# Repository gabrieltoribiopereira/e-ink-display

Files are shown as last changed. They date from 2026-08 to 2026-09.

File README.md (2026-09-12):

# e-ink display

A 7.5" e-paper dashboard that shows the time, the weather, my google calendar, my
google tasks and my habit tracker. An ESP32 wakes up, downloads the image and goes
back to sleep.

# Components

| Universal e-Paper Raw Panel Driver Board, ESP32 WiFi / Bluetooth Wireless | $14,99  |
| --- | --- |
| 800×480, 7.5inch E-Ink display HAT for Raspberry Pi | $47,99  |
| 974058 3000mAh Lipo Battery 3.7V Lithium Polymer Batteries PH2P for Massage Meter GPS Navigator Aeromodelling Rechargeable Cell | 10,99 € |
| 20/50/100PCS/LOT NEW TTP223 Touch Button Module Capacitor Type Single Channel Self Locking Touch Switch Sensor for Arduino | 2,12 €  |
| Frame | 0,00 €  |
| 2/5PCS 5V 1A Micro/Type-c/Mini 18650 TP4056 Lithium Battery Charger Module Charging Board With Protection Dual Functions Li-ion | 1,74€ |
# Explanation

I'll explain some of the tecnical desicions.

First of all I decided to use an esp32 instead of a raspberry pi zero 2 because the
esp32 in its sleep mode consumes so much less electricity.

You can replace the TTP223 for buttons or wathever you like.

The hour will not refresh automaticly because I rather save battery, you have to
wake it first (its not programmed yet because i dont have the esp32 yet).

E-ink keeps the image with **zero power**, that's the whole point. It only costs
battery when it changes. So the esp32 sleeps, wakes up every X minutes, asks if
there is anything new, and only redraws when the image actually changed.

The web renders the screens, a script turns them into a 2 bits per pixel image
(4 grays, 96000 bytes exactly) and the esp32 downloads that raw file. It can't use
a `.h` file because it can't compile anything at runtime, and the `.h` is 6 times
bigger anyway (600KB of text for 96KB of data).

I know that there's 3 buttons in the habit tracker menu that don't work. It's just that
I didn't want to program them because I don't think I will use them. 

# How to install

If you want to replicate the e-ink display there's a lot of thing you need to do.
I'll try my best to explain.

First of all install the repository:

```bash
git clone https://github.com/gabrieltoribiopereira/e-ink-display.git
cd e-ink-display

python3 -m venv .venv
.venv/bin/pip install -r scripts/requirements.txt

cd server && npm ci && npx playwright install --with-deps chromium && cd ..
```

If you are on Arch (or anything that is not Debian/Ubuntu) drop the `--with-deps`,
it uses apt-get behind the scenes so it will fail:

```bash
cd server && npm ci && npx playwright install chromium && cd ..
```

# Supabase

You'll need an account on supabase.com. First of all create a project.

### Create your user

Authentication -> Users -> **Add user**. Write down the email and the password,
you'll need them later. There is no sign up form in the web on purpose, it's only
for me.

### Create the tables

Once the project is created go to SQL editor

paste and execute the following code:

```sql
create table habitos (
  usuario uuid primary key references auth.users(id) on delete cascade,
  datos jsonb not null default '{"habitos":[],"registro":{}}',
  actualizado timestamptz default now()
);
create table ajustes (
  usuario uuid primary key references auth.users(id) on delete cascade,
  ics text, lat numeric default 41.6, lon numeric default 2.3
);
create table tareas (
  usuario uuid primary key references auth.users(id) on delete cascade,
  datos jsonb not null default '[]',
  actualizado timestamptz default now()
);

alter table habitos enable row level security;
alter table ajustes enable row level security;
alter table tareas  enable row level security;

create policy "solo lo mio" on habitos for all
  using (auth.uid() = usuario) with check (auth.uid() = usuario);
create policy "solo lo mio" on ajustes for all
  using (auth.uid() = usuario) with check (auth.uid() = usuario);
create policy "solo lo mio" on tareas for all
  using (auth.uid() = usuario) with check (auth.uid() = usuario);
```

The `enable row level security` part is not optional. The anon key is public (it
goes inside config.js and anyone can read it), so those policies are the only thing
stopping other people from reading your habits and tasks.

### Create the bucket

Storage -> New bucket -> name it `frames`. **Turn OFF the "Public bucket" switch**,
the frames are pictures of your calendar and your tasks.


### Save the keys

Project Settings -> API Keys -> save these two (the `service_role` one is inside
the "Legacy API keys" tab):


Project Settings -> Data API -> save the Project URL. If you can't find it, it's
always `https://<project-ref>.supabase.co` and the ref is in the url of the
dashboard.

# Google

You will need google credentials to use the calendar and the tasks.

### The calendar url

Google Calendar -> my calendars -> 3 dots -> Settings -> **Integrate calendar** ->
copy the **secret address in iCal format**.

Careful with this one, that url is the key to your whole calendar. Anyone who has
it can read all your events without any password.

### The OAuth credentials

console.cloud.google.com -> new project -> **enable the Google Tasks API** first.

Then OAuth consent screen -> **publish the app**. If you leave it in "Testing"
google kills your token every 7 days and the cron stops syncing (it happened to me).

Then Credentials -> Create credentials -> OAuth client ID -> **type: Desktop app**.
The type matters, gtasks.py uses InstalledAppFlow and it only works with Desktop.

Click on the client you just created and hit **Download JSON**. You need the whole
file, not just the client ID.

# The secrets folder

This folder is in .gitignore, that's why you don't see it in the repo. You have to
create it:

```bash
mkdir -p secrets

# the OAuth json you downloaded from google
cp ~/Downloads/client_secret_*.json secrets/credentials.json

# the account the screenshot browser uses to log in.
# same email and password of the supabase user you created before
cat > secrets/display.json <<'EOF'
{"email": "you@example.com", "password": "..."}
EOF

# the ESP32 password. You invent this one, nobody gives it to you
python3 -c "import secrets; print(secrets.token_urlsafe(32))" > secrets/device-token.txt
```

And `secrets/config.js`, which is the one the web reads:

```js
const CONFIG = {
  ICS: "https://calendar.google.com/calendar/ical/.../basic.ics",
  LAT: 41.6,
  LON: 2.3,
  SUPABASE_URL: "https://xxxx.supabase.co",
  SUPABASE_ANON_KEY: "eyJ...",
};
```

There is a template in `web/config.example.js` if you prefer to copy that one.

### Authorize google (only once)

```bash
.venv/bin/python scripts/gtasks.py
```

It opens the browser, you accept, and it creates `secrets/token.json`. From then on
it refreshes by itself, you don't have to authorize again.

# Configure weather

Put your latitude and longitude in `secrets/config.js` (LAT and LON, up there). You
get them from google maps, right click anywhere and it copies them.

The first time you log in, the web copies those values into the `ajustes` table of
supabase and **from then on it reads them from there**, not from config.js. That's
because the ICS url can't live in config.js: that file is served without login, so
on netlify anybody could open /config.js and read your whole calendar.

So if you want to change the location later, config.js will do nothing, you have to
change the table:

```sql
update ajustes set lat = 40.4168, lon = -3.7038;
```

(I named the file ajustes.js instead of settings.js and I don't want to rename it
now that everything works XD, for the next project I'll do everything in english
from the start)

# Github secrets

This part is only if you want it running in the cloud, so the display keeps working
with your computer turned off. Github actions renders the screens every 20 minutes
and uploads them to supabase.

Go to your repo -> Settings -> Secrets and variables -> Actions -> New repository
secret, and create these nine:

| Secret | Where you get it |
|---|---|
| `SUPABASE_URL` | the Project URL from before |
| `SUPABASE_ANON_KEY` | the anon key |
| `SUPABASE_SERVICE_ROLE` | the service_role key (the one that warns about RLS) |
| `CAL_ICS` | the secret iCal url |
| `DISPLAY_EMAIL` | the email of the supabase user |
| `DISPLAY_PASSWORD` | its password |
| `GOOGLE_CREDENTIALS` | the whole content of `secrets/credentials.json` |
| `GOOGLE_TOKEN` | the whole content of `secrets/token.json` |
| `DEVICE_TOKEN` | the same one you put in `secrets/device-token.txt` |

The name goes in the **Name** field (only letters, numbers and `_`, that's why it
rejects an `@`) and the value in the big box below.

# The edge function

The frames bucket is private, so the esp32 can't read it directly. This function
checks its token and gives it the file:

```bash
npx supabase login
npx supabase link --project-ref YOUR_REF
npx supabase secrets set DEVICE_TOKEN=<the same one you generated before>
npx supabase functions deploy frame --no-verify-jwt
```

`--no-verify-jwt` is mandatory. The esp32 has no supabase session, so if you leave
the jwt check on, supabase rejects the request before it even reaches the code.

I didn't give the esp32 the supabase keys on purpose. If someone steals the device
the only thing they can do is download 4 pictures, not read my database.

# Deploy via netlify
(you could use other hosts i chose this because I used before and I'm used to it.)
netlify.com -> Add new site -> Import an existing project -> github -> pick the repo.

**Don't touch** the build command or the publish directory, netlify reads them from
`netlify.toml`.

Before deploying, go to Environment variables and add two:

- `SUPABASE_URL`
- `SUPABASE_ANON_KEY` -> the **anon** one, not the service role

If you paste the wrong one the build fails on purpose with "SUPABASE_ANON_KEY parece
la clave de servicio". I put that check there because that key skips RLS and
publishing it in a static file gives anybody full access to the database.

Then hit Deploy. From now on every git push deploys by itself.

Netlify does **not** replace github actions. The frames still need a real chromium
rendering them and netlify only serves files. Netlify is so I can open the dashboard
from my phone.

# Run it

Now that everything is set up:

```bash
cd server
npm start        # everything: web + chromium + screenshots
npm run web      # only the web, starts instantly, no screenshots
```

Open http://localhost:8002 and log in with the supabase user. Use `npm run web` when
you are just editing the web, it doesn't launch chromium so it's way faster.

Press a button and save the image it returns (this goes in another terminal, change
the x for the button number(1-4)):

```bash
curl -s -X POST -d 'x' http://localhost:8002/boton -o prueba.png 

# see the current screen without pressing anything
curl -s http://localhost:8002/captura.png -o actual.png
```

To test what the esp32 will do:

```bash
.venv/bin/python scripts/simular-esp32.py 1    # press button 1
python3 scripts/ver-bin.py esp32-sim/inicio.bin --abrir
```

Run the same button twice. The second time it should say "sin cambios" and not
download anything, that's the hash check that saves the battery.

Only from the `inicio` screen you can jump to another screen. From the rest, button
1 takes you back and the others do things inside that screen.

If the port gets stuck: `fuser -k 8002/tcp`

## Hardware setup

Connect everything the same way that in CAD/Schematic. Print the case that is located in CAD/case, I encourage you to create your own case because I'm not an expert using cad sofware so the design is not perfect. 

## ESP32 setup

The firmware lives in "esp32/esp32.ino". It wakes up, downloads the frames from supabase, draws the screen and goes back to deepsleep. The buttons switch screens without wifi, everything is alredy stored in the flash.

### Install Arduino IDE

### Create esp32/config.h
This file is in .gitignore on purpose, it carries your wifi password and the device token. Open `esp32/esp32.ino` in the IDE (File -> Open), then create the config next to it: click the three dots at the right of the tab bar -> New Tab,name it `config.h` and paste:

```cpp
#pragma once
#define WIFI_SSID     "YourWifi"
#define WIFI_PASS     "your-password"
#define DEVICE_TOKEN  "the same one from secrets/device-token.txt"
#define FRAMES_URL    "https://xxxx.supabase.co/functions/v1/frame"
#define INTERVAL_S    (20 * 60)
#define FOUR_GRAYS    1
```

### flash it 

connect the display's flat cable to the driver board. Then plug the usb. 

In the IDE:

1. Tools-> Board esp32 -> **Esp32 Dev Module**
2. Tools-> Port-> pick the one that appears when you plug the board
3. Press the **upload** button.

### Check that it works open tools -> serial monitor and set it to **115200 baud**. Press the EN button on the board to see it boot from the start. First boot should look like this:

```
Wake 1: first boot
Connecting to WiFi.... connected, IP 192.168.1.42
  inicio            downloaded
  calendario        downloaded
  calendario-semana downloaded
  todo              downloaded
  habitos           downloaded
Sync done: 5 of 5 updated
Drawing inicio
Going to sleep
```

---

If there is something about I wast clear enough let me know please. I wrote the
readme after finish the project so I may had forget some steps.

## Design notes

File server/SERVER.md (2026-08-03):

# Explicación de como usar el server

El server sirve la web de `web/`, la abre en un Chromium propio y captura
`.contenedor` para generar los `.h` que consume el ESP32.

Puerto: **8002**

## 0 requisito: cuenta del display

La web tiene login, y el navegador que abre el server arranca sin sesión.
Hay que darle una cuenta dedicada en `secrets/display.json`:

```json
{ "email": "display@ejemplo.com", "password": "..." }
```

Sin ese archivo el server arranca igual, pero `/boton` y `/captura.png`
devuelven error porque el dashboard está oculto.

## 1 empezar el server:

```
cd server
npm start          # o: node server.js
```

Luego abre <http://localhost:8002>.

### solo ver la web (sin capturas)

```
npm run web        # o: node server.js --solo-web
```

Arranca al instante porque no lanza Chromium. Sirve la web igual, pero
`/boton` y `/captura.png` devuelven 503. Es el modo para maquetar.

> No vale abrir `web/index.html` a pelo con `file://`: `config.js` se sirve
> desde `secrets/` y `tareas.json` desde `data/`, ninguno de los dos esta
> dentro de `web/`. Ademas Supabase Auth necesita un origen `http`.

## 1.5 tareas de Google Tasks

El server sincroniza `data/tareas.json` solo, sin que tengas que ejecutar nada:

- al arrancar
- cada 10 minutos en segundo plano
- justo antes de capturar la pantalla To-Do (y le pide a la página que recargue)

Como mucho llama a Google una vez cada 10 min, aunque captures sin parar.

**Requisito:** `secrets/token.json`. Se crea la primera vez, autorizando a mano:

```
.venv/bin/python scripts/gtasks.py
```

Ojo con el intérprete: `gtasks.py` necesita el del **venv** (tiene las librerías de
Google), y `convertirimagenendosbits.py` el del **sistema** (tiene Pillow).
Ninguno de los dos sirve para ambos.

Sin `token.json` el server arranca igual y avisa por consola; el resto sigue
funcionando, solo que el To-Do se queda con los últimos datos guardados.

## 2 ejecutar botón:
se tiene que hacer en otra terminal:

```
curl -X POST http://localhost:8002/boton -d "2" -o boton2.png
```

Las capturas y los `.h` se guardan solos en `output/`.

## 3 ver la pantalla actual sin pulsar nada:

```
curl -s http://localhost:8002/captura.png -o actual.png
```

## 4(extra) ejecutar en segundo plano

```
node server.js &
```

## en caso de que haya otro server hay que matarlo:

```
fuser -k 8002/tcp
```

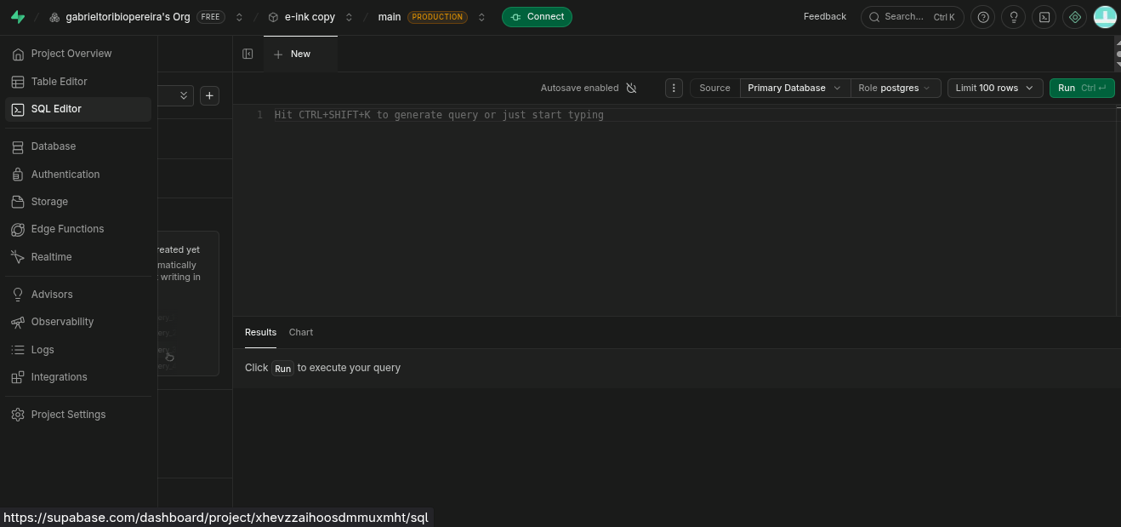
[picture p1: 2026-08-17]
images/image.png

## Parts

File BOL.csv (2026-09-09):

Name | Price | Ship expenses | Link
Universal e-Paper Raw Panel Driver Board, ESP32 WiFi / Bluetooth Wireless | $14,99 |  | https://www.waveshare.com/e-paper-esp32-driver-board.htm
800×480, 7.5inch E-Ink display HAT for Raspberry Pi | $47,99 | $14,00 | https://www.waveshare.com/product/7.5inch-e-paper.htm
974058 3000mAh Lipo Battery 3.7V Lithium Polymer Batteries PH2P for Massage Meter GPS Navigator Aeromodelling Rechargeable Cell | 10,99 € |  | https://es.aliexpress.com/item/1005008979897440.html?mp=1
20/50/100PCS/LOT NEW TTP223 Touch Button Module Capacitor Type Single Channel Self Locking Touch Switch Sensor for Arduino | 2,12 € | 8,14 € | https://es.aliexpress.com/item/1005006246380749.html?mp=1&gatewayAdapt=glo2esp
Frame | 0,00 € | 0 | https://www.leroymerlin.es/productos/marco-natural-wood-natural-13x18cm-71670242.html
2/5PCS 5V 1A Micro/Type-c/Mini 18650 TP4056 Lithium Battery Charger Module Charging Board With Protection Dual Functions Li-ion | 1,74€ |  | https://es.aliexpress.com/item/1005006043031985.html
Total: | €89,43
$ Total: | $103,62
0,8631

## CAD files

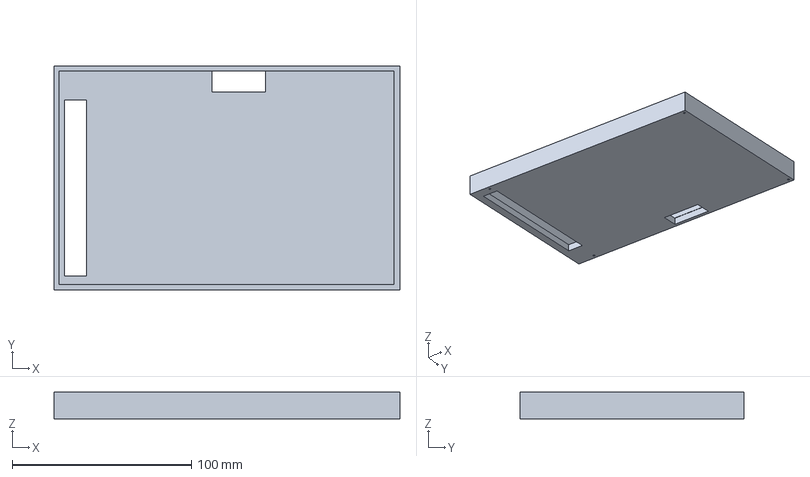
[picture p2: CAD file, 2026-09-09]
CAD/case/body.3mf
193.1 x 125.1 x 15.0 mm

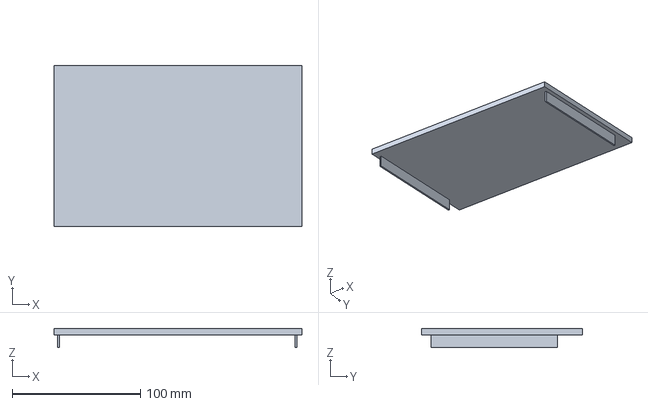
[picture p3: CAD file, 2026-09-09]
CAD/case/back.3mf
193.1 x 125.0 x 15.0 mm

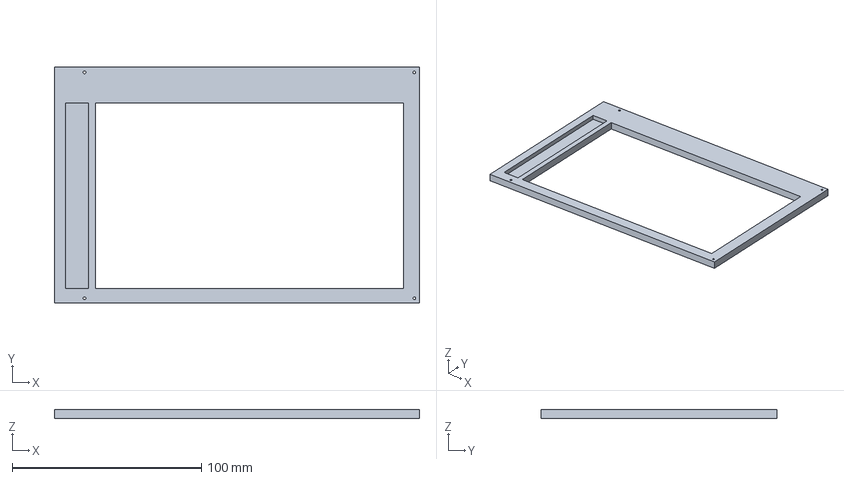
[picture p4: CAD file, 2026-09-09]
CAD/case/frame001.3mf
193.1 x 125.1 x 5.00 mm

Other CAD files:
CAD/case/frame.stl
CAD/case/back.stl
CAD/case/body.stl

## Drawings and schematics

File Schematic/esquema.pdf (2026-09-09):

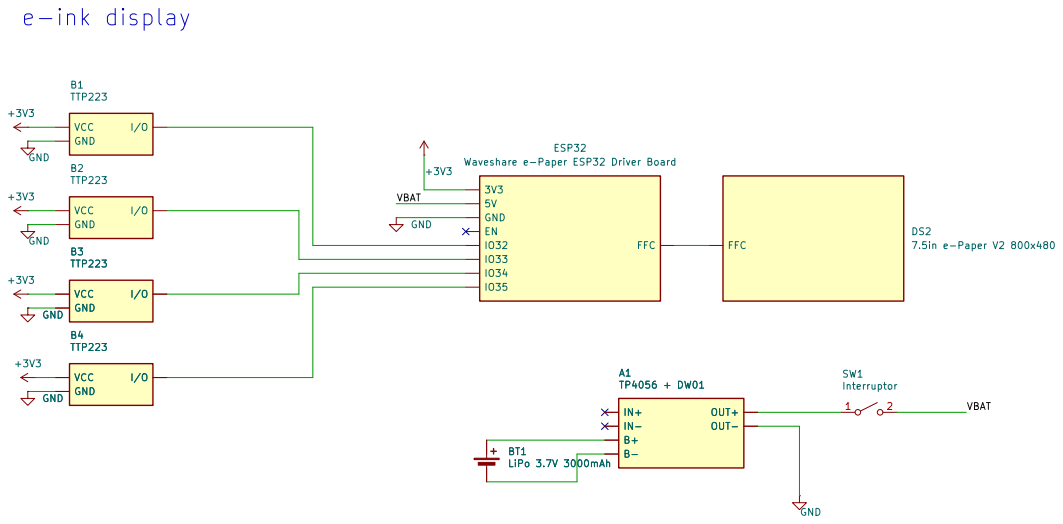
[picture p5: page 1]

ESP32 Waveshare e-Paper ESP32 Driver Board BT1

Modulos comerciales: no hay PCB que fabricar
Panel 7.5in e-Paper V2 + Waveshare ESP32 Driver Board

Sheet: /
File: esquema.kicad_sch
Title: e-ink display - conexiones

Size: A3 | Rev: 1 | F Date:
KiCad E.D.A. 10.0.5 | Id: 1/1

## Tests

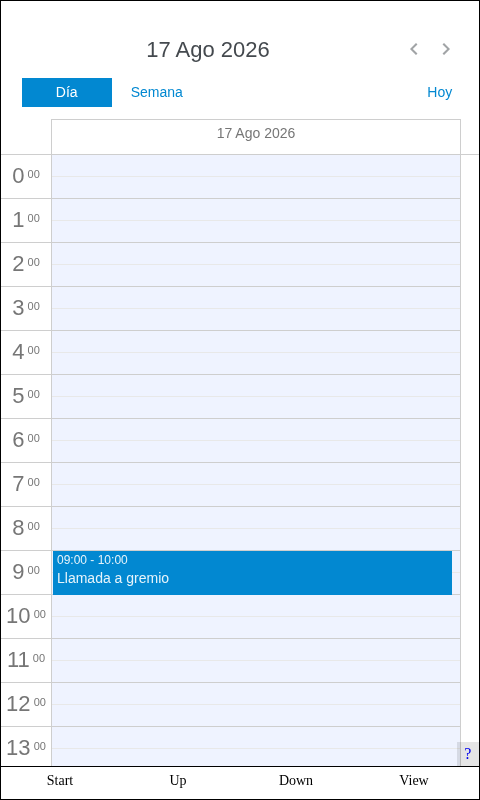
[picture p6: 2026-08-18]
images/prueba.png

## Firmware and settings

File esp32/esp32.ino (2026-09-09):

#include "config.h"
#include <WiFi.h>
#include <WiFiClientSecure.h>
#include <HTTPClient.h>
#include <ArduinoJson.h>
#include <LittleFS.h>
#include <SPI.h>
#include <mbedtls/sha256.h>

const int PIN_CLK = 13, PIN_DIN = 14, PIN_CS = 15;
const int PIN_BUSY = 25, PIN_RST = 26, PIN_DC = 27;
const int BUTTONS[4] = {32, 33, 34, 35};

const char* SCREENS[] = {"inicio", "calendario", "calendario-semana", "todo", "habitos"};
const int NUM_SCREENS = 5;
const int FRAME_BYTES = 800 * 480 * 2 / 8;

RTC_DATA_ATTR int wakeCount = 0;
RTC_DATA_ATTR int currentScreen = 0;

void cmd(uint8_t c) {
  digitalWrite(PIN_DC, LOW);
  digitalWrite(PIN_CS, LOW);
  SPI.transfer(c);
  digitalWrite(PIN_CS, HIGH);
}

void data(const uint8_t* d, int n) {
  digitalWrite(PIN_DC, HIGH);
  digitalWrite(PIN_CS, LOW);
  for (int i = 0; i < n; i++) SPI.transfer(d[i]);
  digitalWrite(PIN_CS, HIGH);
}

void cmdData(uint8_t c, const uint8_t* d, int n) { cmd(c); data(d, n); }

bool waitBusy(uint32_t limit = 40000) {
  uint32_t t0 = millis();
  while (true) {
    cmd(0x71);
    if (digitalRead(PIN_BUSY)) return true;
    if (millis() - t0 > limit) return false;
    delay(20);
  }
}

void resetPanel() {
  digitalWrite(PIN_RST, HIGH); delay(20);
  digitalWrite(PIN_RST, LOW);  delay(2);
  digitalWrite(PIN_RST, HIGH); delay(20);
}

void epdInit(bool fourGrays) {
  resetPanel();
  if (fourGrays) {
    const uint8_t panel[]   = { 0x1F };
    const uint8_t vcom[]    = { 0x10, 0x07 };
    const uint8_t booster[] = { 0x27, 0x27, 0x18, 0x17 };
    const uint8_t e0[] = { 0x02 }, e5[] = { 0x5F };
    cmdData(0x00, panel, 1);
    cmdData(0x50, vcom, 2);
    cmd(0x04); delay(100); waitBusy();
    cmdData(0x06, booster, 4);
    cmdData(0xE0, e0, 1);
    cmdData(0xE5, e5, 1);
  } else {
    const uint8_t power[]   = { 0x07, 0x07, 0x3f, 0x3f };
    const uint8_t booster[] = { 0x17, 0x17, 0x27, 0x17 };
    const uint8_t panel[]   = { 0x1F };
    const uint8_t res[]     = { 0x03, 0x20, 0x01, 0xE0 };
    const uint8_t dual[]    = { 0x00 };
    const uint8_t vcom[]    = { 0x10, 0x07 };
    const uint8_t tcon[]    = { 0x22 };
    cmdData(0x01, power, 4);
    cmdData(0x06, booster, 4);
    cmd(0x04); delay(100); waitBusy();
    cmdData(0x00, panel, 1);
    cmdData(0x61, res, 4);
    cmdData(0x15, dual, 1);
    cmdData(0x50, vcom, 2);
    cmdData(0x60, tcon, 1);
  }
}

void epdSleep() {
  const uint8_t border[] = { 0xF7 };
  const uint8_t a5[]     = { 0xA5 };
  cmdData(0x50, border, 1);
  cmd(0x02); waitBusy();
  cmdData(0x07, a5, 1);
}

void writePlane(File& f, uint8_t command, const uint8_t bit[4]) {
  uint8_t table[256];
  for (int b = 0; b < 256; b++) {
    uint8_t v = 0;
    for (int k = 0; k < 4; k++) {
      int level = (b >> (6 - 2 * k)) & 3;
      v = (v << 1) | bit[level];
    }
    table[b] = v;
  }

  static uint8_t inBuf[2048], outBuf[1024];
  f.seek(0);
  cmd(command);
  digitalWrite(PIN_DC, HIGH);
  digitalWrite(PIN_CS, LOW);
  int n;
  while ((n = f.read(inBuf, sizeof(inBuf))) > 0) {
    for (int i = 0; i < n; i += 2)
      outBuf[i >> 1] = (table[inBuf[i]] << 4) | table[inBuf[i + 1]];
    SPI.writeBytes(outBuf, n >> 1);
  }
  digitalWrite(PIN_CS, HIGH);
}

bool drawScreen(const char* name) {
  File f = LittleFS.open(String("/") + name + ".bin", "r");
  if (!f || f.size() != FRAME_BYTES) {
    Serial.printf("no valid frame for %s\n", name);
    return false;
  }
  Serial.printf("Drawing %s\n", name);

  epdInit(FOUR_GRAYS);
  if (FOUR_GRAYS) {
    const uint8_t plane10[4] = {1, 0, 1, 0};
    const uint8_t plane13[4] = {1, 1, 0, 0};
    writePlane(f, 0x10, plane10);
    writePlane(f, 0x13, plane13);
  } else {
    const uint8_t plane10[4] = {0, 0, 1, 1};
    const uint8_t plane13[4] = {1, 1, 0, 0};
    writePlane(f, 0x10, plane10);
    writePlane(f, 0x13, plane13);
  }
  f.close();

  cmd(0x12); delay(100);
  bool ok = waitBusy();
  epdSleep();
  return ok;
}

bool connectWiFi() {
  WiFi.mode(WIFI_STA);
  WiFi.begin(WIFI_SSID, WIFI_PASS);
  Serial.print("Connecting to WiFi");

  unsigned long start = millis();
  while (WiFi.status() != WL_CONNECTED) {
    if (millis() - start > 15000) {
      Serial.println(" failed, giving up");
      return false;
    }
    delay(250);
    Serial.print(".");
  }

  Serial.printf(" connected, IP %s\n", WiFi.localIP().toString().c_str());
  return true;
}

String fetchManifest() {
  WiFiClientSecure client;
  client.setInsecure();

  HTTPClient http;
  http.begin(client, FRAMES_URL);
  http.addHeader("x-device-token", DEVICE_TOKEN);

  int code = http.GET();
  if (code != 200) {
    Serial.printf("Manifest request failed: HTTP %d\n", code);
    http.end();
    return "";
  }

  String body = http.getString();
  http.end();
  return body;
}

void toHex(const uint8_t* d, char* out) {
  const char* h = "0123456789abcdef";
  for (int i = 0; i < 32; i++) {
    out[i * 2]     = h[d[i] >> 4];
    out[i * 2 + 1] = h[d[i] & 15];
  }
  out[64] = 0;
}

bool downloadFrameOnce(const char* name, int expectedBytes, const char* expectedHash) {
  WiFiClientSecure client;
  client.setInsecure();

  HTTPClient http;
  http.begin(client, String(FRAMES_URL) + "?p=" + name);
  http.addHeader("x-device-token", DEVICE_TOKEN);

  int code = http.GET();
  if (code != 200) {
    Serial.printf("  %s: HTTP %d\n", name, code);
    http.end();
    return false;
  }

  String tmpPath = String("/") + name + ".tmp";
  File f = LittleFS.open(tmpPath, "w");
  if (!f) {
    http.end();
    return false;
  }

  mbedtls_sha256_context sha;
  mbedtls_sha256_init(&sha);
  mbedtls_sha256_starts(&sha, 0);

  WiFiClient* stream = http.getStreamPtr();
  static uint8_t buf[2048];
  int total = 0;
  unsigned long start = millis();

  while (total < expectedBytes && millis() - start < 30000) {
    int n = stream->read(buf, sizeof(buf));
    if (n > 0) {
      f.write(buf, n);
      mbedtls_sha256_update(&sha, buf, n);
      total += n;
    } else {
      delay(1);
    }
  }
  f.close();
  http.end();

  uint8_t digest[32];
  char hex[65];
  mbedtls_sha256_finish(&sha, digest);
  mbedtls_sha256_free(&sha);
  toHex(digest, hex);

  if (total != expectedBytes || strcmp(hex, expectedHash) != 0) {
    Serial.printf("  %s: corrupt download (%d bytes)\n", name, total);
    LittleFS.remove(tmpPath);
    return false;
  }

  String binPath = String("/") + name + ".bin";
  LittleFS.remove(binPath);
  LittleFS.rename(tmpPath, binPath);
  return true;
}

bool downloadFrame(const char* name, int expectedBytes, const char* expectedHash) {
  for (int attempt = 1; attempt <= 3; attempt++) {
    if (downloadFrameOnce(name, expectedBytes, expectedHash)) return true;
    if (attempt < 3) {
      Serial.printf("  %s: retry %d\n", name, attempt);
      delay(3000);
    }
  }
  return false;
}

String savedHash(const char* name) {
  File f = LittleFS.open(String("/") + name + ".hash", "r");
  if (!f) return "";
  String h = f.readString();
  f.close();
  return h;
}

void saveHash(const char* name, const char* hash) {
  File f = LittleFS.open(String("/") + name + ".hash", "w");
  if (!f) return;
  f.print(hash);
  f.close();
}

bool syncFrames() {
  if (!connectWiFi()) return false;

  String manifest = fetchManifest();
  for (int t = 0; t < 2 && manifest == ""; t++) {
    delay(3000);
    manifest = fetchManifest();
  }
  if (manifest == "") return false;

  JsonDocument doc;
  DeserializationError err = deserializeJson(doc, manifest);
  if (err) {
    Serial.println("Manifest is not valid JSON");
    return false;
  }

  bool currentChanged = false;
  int updated = 0;
  for (int i = 0; i < NUM_SCREENS; i++) {
    const char* hash = doc["pantallas"][SCREENS[i]]["hash"];
    int bytes = doc["pantallas"][SCREENS[i]]["bytes"] | 0;
    if (hash == NULL || bytes != FRAME_BYTES) {
      Serial.printf("  %-17s missing or wrong size in manifest!\n", SCREENS[i]);
      continue;
    }
    if (savedHash(SCREENS[i]) == hash) {
      Serial.printf("  %-17s no changes\n", SCREENS[i]);
      continue;
    }
    if (downloadFrame(SCREENS[i], bytes, hash)) {
      saveHash(SCREENS[i], hash);
      Serial.printf("  %-17s downloaded\n", SCREENS[i]);
      updated++;
      if (i == currentScreen) currentChanged = true;
    }
  }
  Serial.printf("Sync done: %d of %d updated\n", updated, NUM_SCREENS);

  WiFi.disconnect(true);
  WiFi.mode(WIFI_OFF);
  return currentChanged;
}

int indexOf(const char* name) {
  for (int i = 0; i < NUM_SCREENS; i++)
    if (strcmp(SCREENS[i], name) == 0) return i;
  return 0;
}

int navigate(int current, int button) {
  const char* name = SCREENS[current];
  if (strcmp(name, "inicio") == 0) {
    if (button == 2) return indexOf("calendario");
    if (button == 3) return indexOf("todo");
    if (button == 4) return indexOf("habitos");
    return current;
  }
  if (button == 1) return indexOf("inicio");
  if (strcmp(name, "calendario") == 0 && button == 4) return indexOf("calendario-semana");
  if (strcmp(name, "calendario-semana") == 0 && button == 4) return indexOf("calendario");
  return current;
}

int buttonPressed() {
  uint64_t mask = esp_sleep_get_ext1_wakeup_status();
  for (int i = 0; i < 4; i++)
    if (mask & (1ULL << BUTTONS[i])) return i + 1;
  return 0;
}

void goToSleep() {
  Serial.println("Going to sleep");
  uint64_t mask = 0;
  for (int i = 0; i < 4; i++) mask |= 1ULL << BUTTONS[i];
  esp_sleep_enable_ext1_wakeup(mask, ESP_EXT1_WAKEUP_ANY_HIGH);
  esp_sleep_enable_timer_wakeup((uint64_t)INTERVAL_S * 1000000ULL);
  Serial.flush();
  esp_deep_sleep_start();
}

void setup() {
  Serial.begin(115200);
  delay(300);

  pinMode(PIN_CS, OUTPUT);  digitalWrite(PIN_CS, HIGH);
  pinMode(PIN_DC, OUTPUT);  digitalWrite(PIN_DC, LOW);
  pinMode(PIN_RST, OUTPUT); digitalWrite(PIN_RST, HIGH);
  pinMode(PIN_BUSY, INPUT);
  for (int i = 0; i < 4; i++) pinMode(BUTTONS[i], INPUT);

  SPI.begin(PIN_CLK, -1, PIN_DIN, PIN_CS);
  SPI.beginTransaction(SPISettings(10000000, MSBFIRST, SPI_MODE0));

  if (!LittleFS.begin(true)) {
    Serial.println("LittleFS failed!");
    goToSleep();
  }
  wakeCount++;

  esp_sleep_wakeup_cause_t cause = esp_sleep_get_wakeup_cause();

  if (cause == ESP_SLEEP_WAKEUP_EXT1) {
    int button = buttonPressed();
    int next = navigate(currentScreen, button);
    Serial.printf("Wake %d: button %d -> %s\n", wakeCount, button, SCREENS[next]);
    if (next != currentScreen) {
      currentScreen = next;
      drawScreen(SCREENS[currentScreen]);
    }
  } else if (cause == ESP_SLEEP_WAKEUP_TIMER) {
    Serial.printf("Wake %d: timer, time to sync\n", wakeCount);
    if (syncFrames()) drawScreen(SCREENS[currentScreen]);
  } else {
    Serial.printf("Wake %d: first boot\n", wakeCount);
    syncFrames();
    drawScreen(SCREENS[currentScreen]);
  }

  goToSleep();
}

void loop() {
}

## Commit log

2026-07-21 he añadido el la fecha, la hora, unos recuadros que simulan los botones y el clima con los grados y un simbolo
2026-07-21 he eliminado los archivos extra
    [.wakatime.cfg]
2026-07-22 he añadido la barra de abajo junto a las funciones de calendario
2026-07-22 Tareas de Google Tasks, barra inferior y control del calendario
2026-07-30 Todo funcionando antes del cambio de organización
2026-07-30 Estructura mejorada. Hay que hacer unas cuantas modificaciones; 1. ver la manera de implementar todo desde la carpeta principal y no desde web. 2. Implementar server(server funciona pero hay que impl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
2026-08-03 Frames en la nube: workflow, subidor y Edge Function
2026-08-04 Mensajes de error claros en el subidor
2026-08-04 Datos personales a Supabase: web lista para desplegar
2026-08-17 Update README with button number range clarification
    Clarify button number range in README instructions.
2026-08-20 Render both calendar views so the ESP32 can switch offline
2026-09-09 esp32 code
2026-09-09 esp-32 code
    [BOL.csv]
2026-09-12 Enhance README with ESP32 setup instructions
    Added detailed ESP32 setup instructions, including how to install the Arduino IDE, create a config file, and flash the firmware. Included example code for the config.h file and initial boot output.
